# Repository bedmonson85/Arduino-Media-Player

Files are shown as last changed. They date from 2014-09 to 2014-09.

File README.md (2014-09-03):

Arduino-Media-Player
====================
This is currently a place to keep up with my eagle cad files for my project:
Atmega328p /w Arduino UNO bootloader based media player design. 
It is currently unfinished -- a work in progress.  After schematic and board are finished
I'll begin work on the code.

Released under the Creative Commons Attribution Share-Alike 4.0 License.
https:/creativecommons.org/licenses/by-sa/4.0/

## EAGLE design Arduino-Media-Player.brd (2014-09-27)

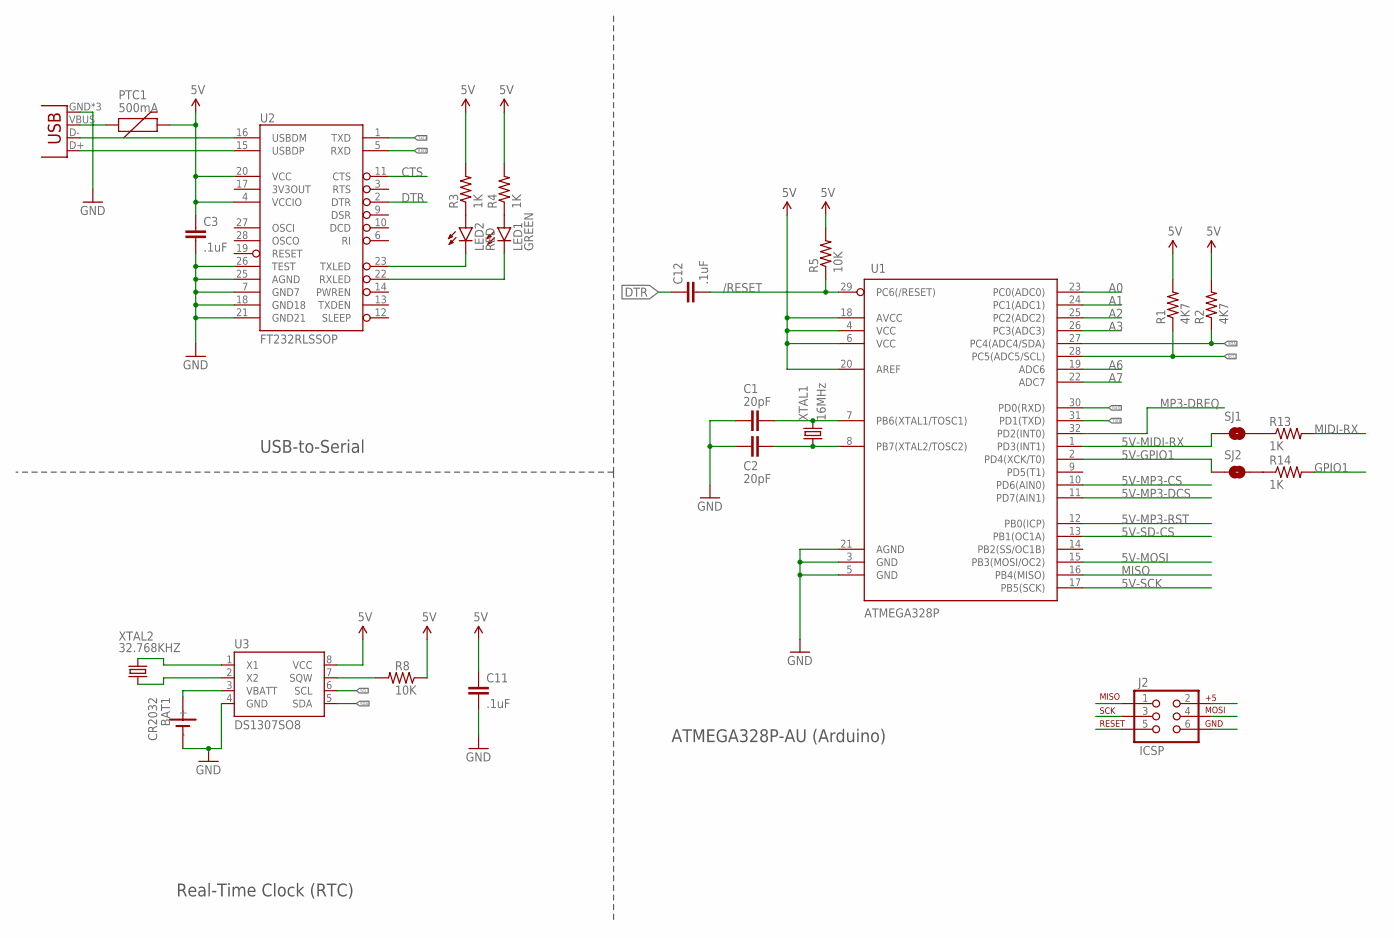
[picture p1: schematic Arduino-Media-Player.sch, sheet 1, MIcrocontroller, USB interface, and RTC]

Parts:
BAT1: CR2032; SN2032
C1, C2: 20pF; 1206
C3, C11, C12: .1uF; 0805
J2: ICSP; 2X3
LED1: GREEN; LED-0603
LED2: RED; LED-0603
PTC1: 500mA; 0805
R1, R2: 4K7; 0805
R3, R4, R13, R14: 1K; 0805
R5: 10K; 0805
R8: 10K; R0805W
SJ1, SJ2: JUMPER-PAD-2-NOROUND; PAD-JUMPER-2-NO_YES_SILK_ROUND
U1: ATMEGA328P; TQFP32-08
U2: FT232RLSSOP; SSOP28DB
U3: DS1307SO8; SO08
USB1: USB-MICROB
XTAL1: 16MHz; CRYSTAL-SMD-10.5X4.8-2PIN
XTAL2: 32.768KHZ; CRYSTAL-32KHZ-SMD

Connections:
5V: C3.1, C11.1, J2.2, PTC1.2, R1.2, R2.2, R3.2, R4.2, R5.2, R8.1, U1.4 (VCC), U1.6 (VCC), U1.18 (AVCC), U1.20 (AREF), U2.4 (VCCIO), U2.20 (VCC), U3.8 (VCC); also elsewhere on the board
5V-GPIO1: SJ2.1, U1.2 (PD4(XCK/T0))
5V-MIDI-RX: SJ1.1, U1.1 (PD3(INT1))
5V-MOSI: J2.4, U1.15 (PB3(MOSI/OC2)); also elsewhere on the board
5V-MP3-CS: U1.10 (PD6(AIN0)); also elsewhere on the board
5V-MP3-DCS: U1.11 (PD7(AIN1)); also elsewhere on the board
5V-MP3-RST: U1.12 (PB0(ICP)); also elsewhere on the board
5V-SCK: J2.3, U1.17 (PB5(SCK)); also elsewhere on the board
5V-SD-CS: U1.13 (PB1(OC1A)); also elsewhere on the board
/RESET: C12.2, J2.5, R5.1, U1.29 (PC6(/RESET))
A0: U1.23 (PC0(ADC0))
A1: U1.24 (PC1(ADC1))
A2: U1.25 (PC2(ADC2))
A3: U1.26 (PC3(ADC3))
A6: U1.19 (ADC6)
A7: U1.22 (ADC7)
CTS: U2.11 (CTS)
DS1307X1: U3.1 (X1), XTAL2.X2 (2)
DS1307X2: U3.2 (X2), XTAL2.X1 (1)
DTR: C12.1, U2.2 (DTR)
GND: BAT1.-, C1.1, C2.1, C3.2, C11.2, J2.6, U1.3 (GND), U1.5 (GND), U1.21 (AGND), U2.7 (GND7), U2.18 (GND18), U2.21 (GND21), U2.25 (AGND), U2.26 (TEST), U3.4 (GND), USB1.GND, USB1.MT1 (GND), USB1.MT2 (GND); also elsewhere on the board
GPIO1: R14.2; also elsewhere on the board
MIDI-RX: R13.2; also elsewhere on the board
MISO: J2.1, U1.16 (PB4(MISO)); also elsewhere on the board
MP3-DREQ: U1.32 (PD2(INT0)); also elsewhere on the board
unnamed: R13.1, SJ1.2
unnamed: R14.1, SJ2.2
unnamed: C1.2, U1.7 (PB6(XTAL1/TOSC1)), XTAL1.P$2 (2)
unnamed: C2.2, U1.8 (PB7(XTAL2/TOSC2)), XTAL1.P$1 (1)
unnamed: LED2.A, R3.1
unnamed: LED1.A, R4.1
unnamed: LED2.C, U2.23 (TXLED)
unnamed: LED1.C, U2.22 (RXLED)
unnamed: U2.16 (USBDM), USB1.D-
unnamed: U2.15 (USBDP), USB1.D+
RXD: U1.30 (PD0(RXD)), U2.5 (RXD)
SCL: R1.1, U1.28 (PC5(ADC5/SCL)), U3.6 (SCL)
SDA: R2.1, U1.27 (PC4(ADC4/SDA)), U3.5 (SDA)
SQW: R8.2, U3.7 (SQW)
TXD: U1.31 (PD1(TXD)), U2.1 (TXD)
VBATT: BAT1.+, U3.3 (VBATT)
VBUS: PTC1.1, USB1.VBUS

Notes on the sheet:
USB-to-Serial
Real-Time Clock (RTC)
ATMEGA328P-AU (Arduino)

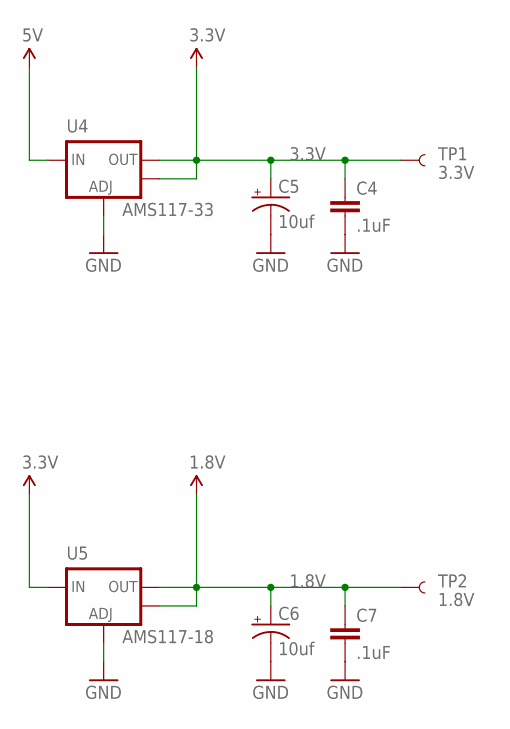
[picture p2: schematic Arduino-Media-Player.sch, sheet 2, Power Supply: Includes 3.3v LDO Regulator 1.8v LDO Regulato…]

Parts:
C4, C7: .1uF; 0805
C5, C6: 10uf; PANASONIC_C
TP1: 3.3V; PAD.03X.04
TP2: 1.8V; PAD.03X.04
U4: AMS117-33; SOT223
U5: AMS117-18; SOT223

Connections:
1.8V: C6.+, C7.1, TP2.P$1, U5.2 (OUT), U5.4 (OUT); also elsewhere on the board
3.3V: C4.1, C5.+, TP1.P$1, U4.2 (OUT), U4.4 (OUT), U5.3 (IN); also elsewhere on the board
5V: U4.3 (IN); also elsewhere on the board
GND: C4.2, C5.-, C6.-, C7.2, U4.1 (ADJ), U5.1 (ADJ); also elsewhere on the board

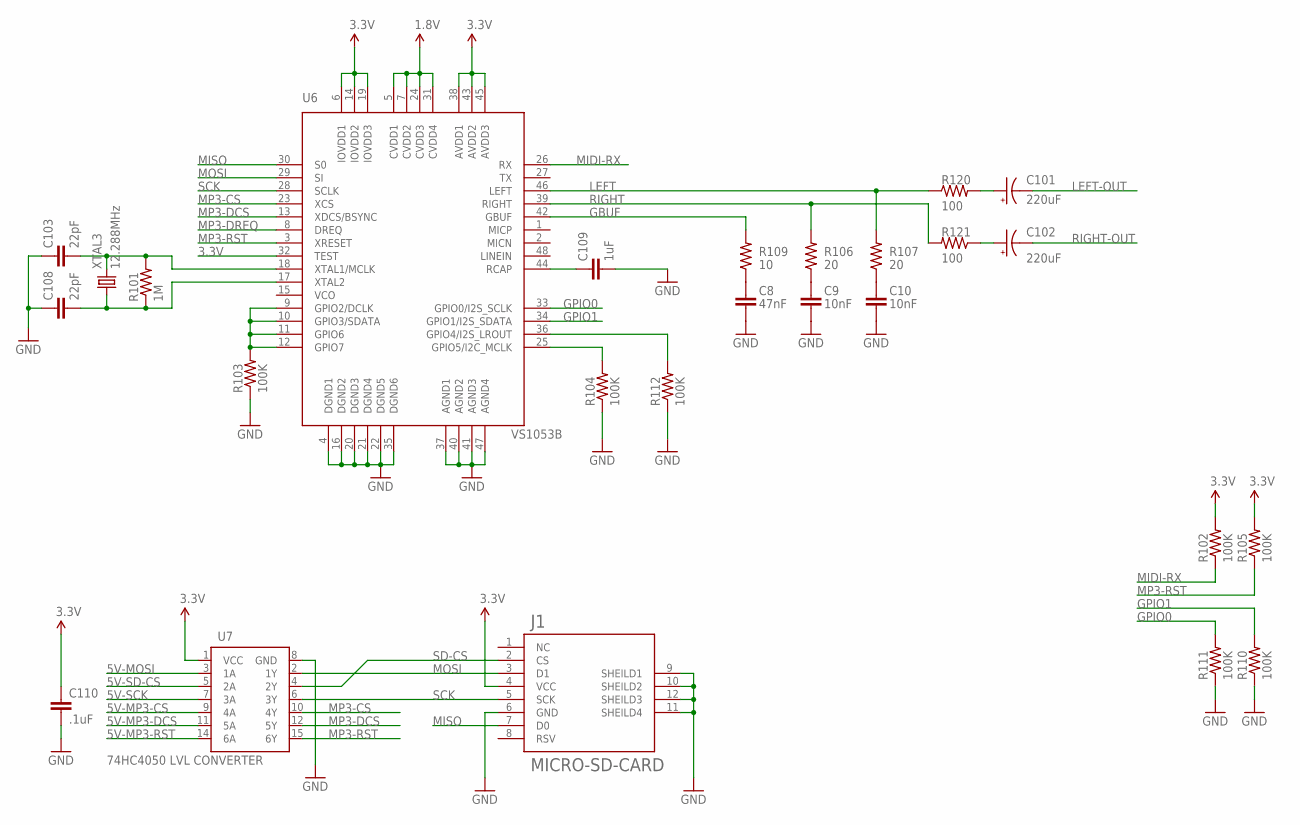
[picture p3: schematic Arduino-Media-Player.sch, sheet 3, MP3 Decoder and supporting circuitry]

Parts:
C8: 47nF; 0805
C9, C10: 10nF; 0805
C101, C102: 220uF; PANASONIC_G
C103, C108: 22pF; 0805
C109: 1uF; 0805
C110: .1uF; 0805
J1: MICRO-SD-CARD; MICRO-SD-EBAY
R101: 1M; 0805
R102, R103, R104, R105, R110, R111, R112: 100K; 0805
R106, R107: 20; 0805
R109: 10; 0805
R120, R121: 100; 0805
U6: VS1053B; LQFP-48
U7: 74HC4050 LVL CONVERTER; SO016
XTAL3: 12.288MHz; CRYSTAL-SMD-10.5X4.8-2PIN

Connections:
1.8V: U6.5 (CVDD1), U6.7 (CVDD2), U6.24 (CVDD3), U6.31 (CVDD4); also elsewhere on the board
3.3V: C110.1, J1.4 (VCC), R102.2, R105.2, U6.6 (IOVDD1), U6.14 (IOVDD2), U6.19 (IOVDD3), U6.32 (TEST), U6.38 (AVDD1), U6.43 (AVDD2), U6.45 (AVDD3), U7.1 (VCC); also elsewhere on the board
5V-MOSI: U7.3 (1A); also elsewhere on the board
5V-MP3-CS: U7.9 (4A); also elsewhere on the board
5V-MP3-DCS: U7.11 (5A); also elsewhere on the board
5V-MP3-RST: U7.14 (6A); also elsewhere on the board
5V-SCK: U7.7 (3A); also elsewhere on the board
5V-SD-CS: U7.5 (2A); also elsewhere on the board
GBUF: R109.2, U6.42 (GBUF)
GND: C8.1, C9.1, C10.1, C103.1, C108.1, C109.2, C110.2, J1.6 (GND), J1.9 (SHEILD1), J1.10 (SHEILD2), J1.11 (SHEILD4), J1.12 (SHEILD3), R103.1, R104.1, R110.1, R111.1, R112.1, U6.4 (DGND1), U6.16 (DGND2), U6.20 (DGND3), U6.21 (DGND4), U6.22 (DGND5), U6.35 (DGND6), U6.37 (AGND1), U6.40 (AGND2), U6.41 (AGND3), U6.47 (AGND4), U7.8 (GND); also elsewhere on the board
GPIO0: R111.2, U6.33 (GPIO0/I2S_SCLK)
GPIO1: R110.2, U6.34 (GPIO1/I2S_SDATA); also elsewhere on the board
LEFT: R107.2, R120.1, U6.46 (LEFT)
LEFT-OUT: C101.-
MIDI-RX: R102.1, U6.26 (RX); also elsewhere on the board
MISO: J1.7 (D0), U6.30 (S0); also elsewhere on the board
MOSI: J1.3 (D1), U6.29 (SI), U7.2 (1Y)
MP3-CS: U6.23 (XCS), U7.10 (4Y)
MP3-DCS: U6.13 (XDCS/BSYNC), U7.12 (5Y)
MP3-DREQ: U6.8 (DREQ); also elsewhere on the board
MP3-RST: R105.1, U6.3 (XRESET), U7.15 (6Y)
unnamed: C101.+, R120.2
unnamed: R104.2, U6.25 (GPIO5/I2C_MCLK)
unnamed: R112.2, U6.36 (GPIO4/I2S_LROUT)
unnamed: C102.+, R121.1
unnamed: C8.2, R109.1
unnamed: R103.2, U6.9 (GPIO2/DCLK), U6.10 (GPIO3/SDATA), U6.11 (GPIO6), U6.12 (GPIO7)
unnamed: C9.2, R106.1
unnamed: C10.2, R107.1
RCAP: C109.1, U6.44 (RCAP)
RIGHT: R106.2, R121.2, U6.39 (RIGHT)
RIGHT-OUT: C102.-
SCK: J1.5 (SCK), U6.28 (SCLK), U7.6 (3Y)
SD-CS: J1.2 (CS), U7.4 (2Y)
VS1053XTAL1: C103.2, R101.2, U6.18 (XTAL1/MCLK), XTAL3.P$2 (2)
VS1053XTAL2: C108.2, R101.1, U6.17 (XTAL2), XTAL3.P$1 (1)

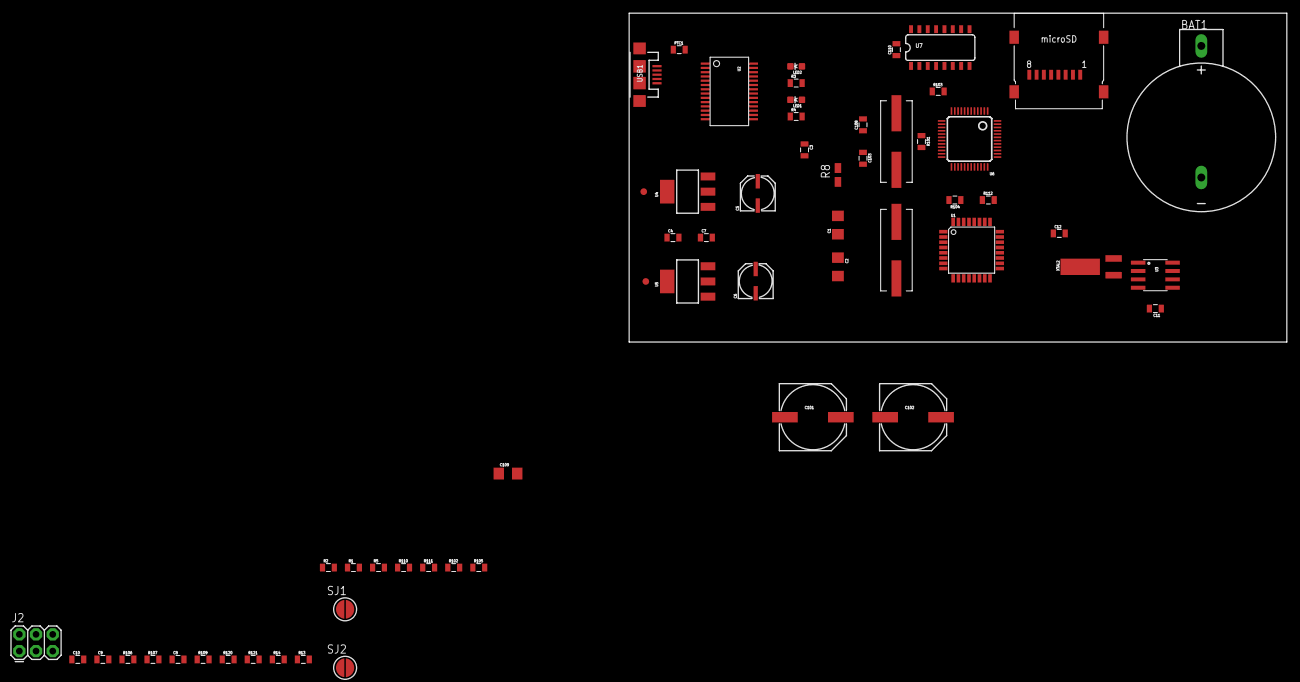
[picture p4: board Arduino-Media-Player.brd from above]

Board: 2 copper layers, 100.0 x 50.0 mm, 60 parts (0 on the bottom side), 58 nets.

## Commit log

2014-09-03 Added eagle cad schematic and board files
    [Arduino-Media-Player.brd, Arduino-Media-Player.sch]
2014-09-21 Few minor changes
    [Arduino-Media-Player.brd, Arduino-Media-Player.sch]
2014-09-21 More minor changes
    [Arduino-Media-Player.sch]
2014-09-27 Added audio output circuitry for mp3 decoder
    [Arduino-Media-Player.brd, Arduino-Media-Player.sch]
2014-09-27 Added ICSP header for ATMEGA328p
    [Arduino-Media-Player.brd, Arduino-Media-Player.sch]

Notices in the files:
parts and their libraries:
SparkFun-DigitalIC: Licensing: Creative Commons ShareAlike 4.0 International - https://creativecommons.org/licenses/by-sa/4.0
